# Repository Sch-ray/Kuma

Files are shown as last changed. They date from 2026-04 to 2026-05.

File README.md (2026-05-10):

Welcome here, and thank you all for your support. This is the public directory of the KUMA project, where some files will be gradually open-sourced.

> [!IMPORTANT]
> Statement: If you like the FlipperZero project and have sufficient financial ability, please purchase the original device through official channels. Building such a strong community is not easy, and we appreciate that they have open-sourced a large amount of materials. My device is not intended for counterfeiting or piracy. It includes targeted modifications and uses a completely new exterior design for clear distinction. The enclosure is fully incompatible with the original device. The purpose is to create a more affordable device and promote better development of the project.

> [!IMPORTANT]
> Additional statement: The device is intended only for legal technical learning and lawful analysis and testing by professionals (you should know what you are doing).

[Shell_Modell](./Shell_Model)
The shell model files are now available. Now you can print more beautiful and personalized cases for yourself 😎! 

This is my YouTube channel
[Youtube](https://www.youtube.com/channel/UCHENkZK1oac_hoAVk4aAufA)

This is my BiliBili channel
[BiliBili](https://space.bilibili.com/150167463)

If you are seeking business collaboration or advice regarding a project, you can contact me via email.
[Email](xiao_hei666@yeah.net)

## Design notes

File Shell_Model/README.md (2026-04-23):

Welcome here, and thanks for your support!
If you own a 3D printer, you can now print a ⭐ better-looking and 😎 more personalized enclosure for yourself!
And if you have enough time, you can also choose finer print settings for higher quality results.

I used **PETG** material for printing. With proper printer settings, the result should come out pretty good.

> [!WARNING]
> Warning: Disassembling the enclosure may damage your device. You are responsible for any risks or consequences.

> [!IMPORTANT]
> Disclaimer: If you like the FlipperZero project and have the financial ability, please consider purchasing the original device through official channels. Building such a strong community is not easy, and they have open-sourced a large amount of valuable information.
> My device is **not** intended for counterfeiting or piracy. It includes targeted modifications and a completely new appearance for clear differentiation. The enclosure and structural parts are **fully incompatible** with the original device.
> The goal is to create a more affordable device and help the project ecosystem grow.

> [!IMPORTANT]
> Additional Disclaimer: This device is intended only for legal technical learning, professional research, and lawful analysis/testing purposes (you should know what you are doing).

---

### Before printing your own enclosure, you should know:

1. Due to cost constraints and limited development resources, the structure is not perfect. Disassembly carries some risk. Please read the instructions carefully and make sure you have steady hands and a solder station.

2. Replacing and installing the enclosure requires hands-on skills. Make sure you are confident before starting. Any damage caused during disassembly is your own responsibility.

3. Make sure your 3D printer build plate is clean and has good adhesion. Some narrow lines and characters require a well-prepared print surface.
   (My early prints failed many times because the build plate wasn’t clean enough.)

4. Be mentally prepared — since the device is hand-assembled and soldered, there will be visible soldering marks inside 🙄.

---

### File Description: Latest Version [V1](./V1)

<sub>*This directory includes 5 parts: Top Shell, Middle Layer, Bottom Shell, Buttons, and Light Pipe.*</sub>

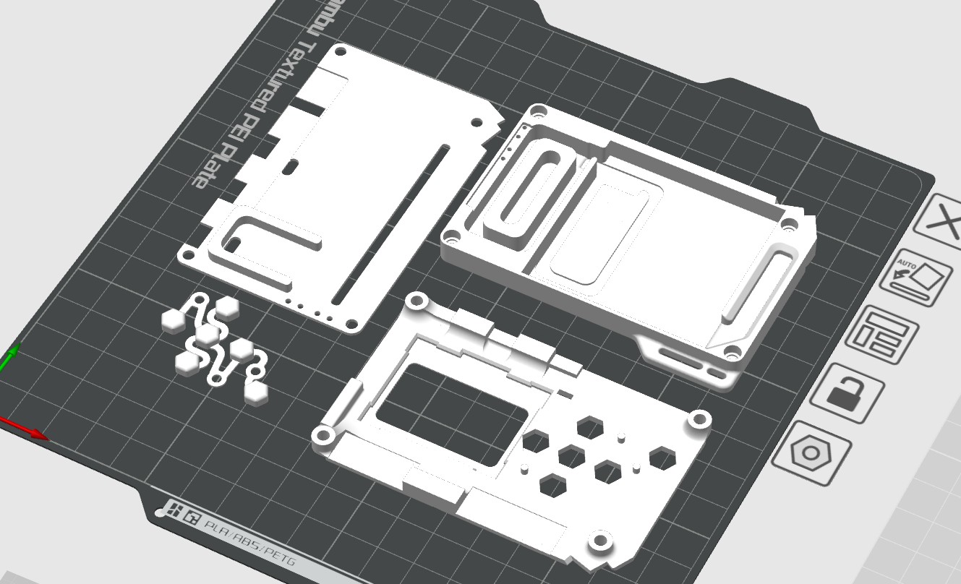
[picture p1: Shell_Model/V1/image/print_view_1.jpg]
print\_view\_1

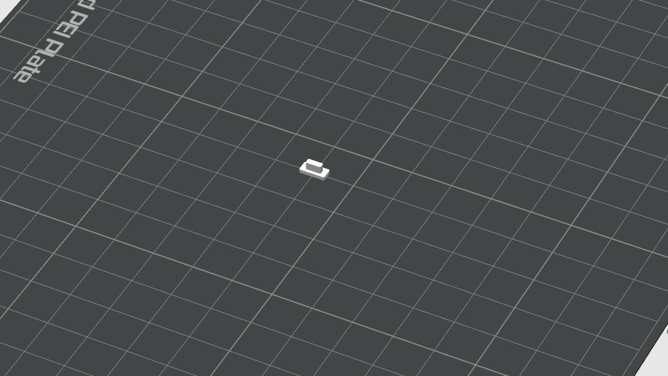
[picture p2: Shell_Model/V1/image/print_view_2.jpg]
print\_view\_1


> [!TIP]
> `LED_Light_Pipe.step` is the front light pipe of the device and should be printed using transparent filament.
> If you don’t have transparent material, you can leave it empty, fill it with semi-transparent glue, or reuse the light pipe from an existing enclosure.

---

### Disassembly and Assembly Instructions:

> [!TIP]
> Before disassembly, touch a grounded metal object nearby or use an anti-static wrist strap to avoid damaging the circuit board with static electricity.

---

**1. Remove the Top Shell**

On the front side of the device, you will find four screws at the corners. Remove them using a hex screwdriver.

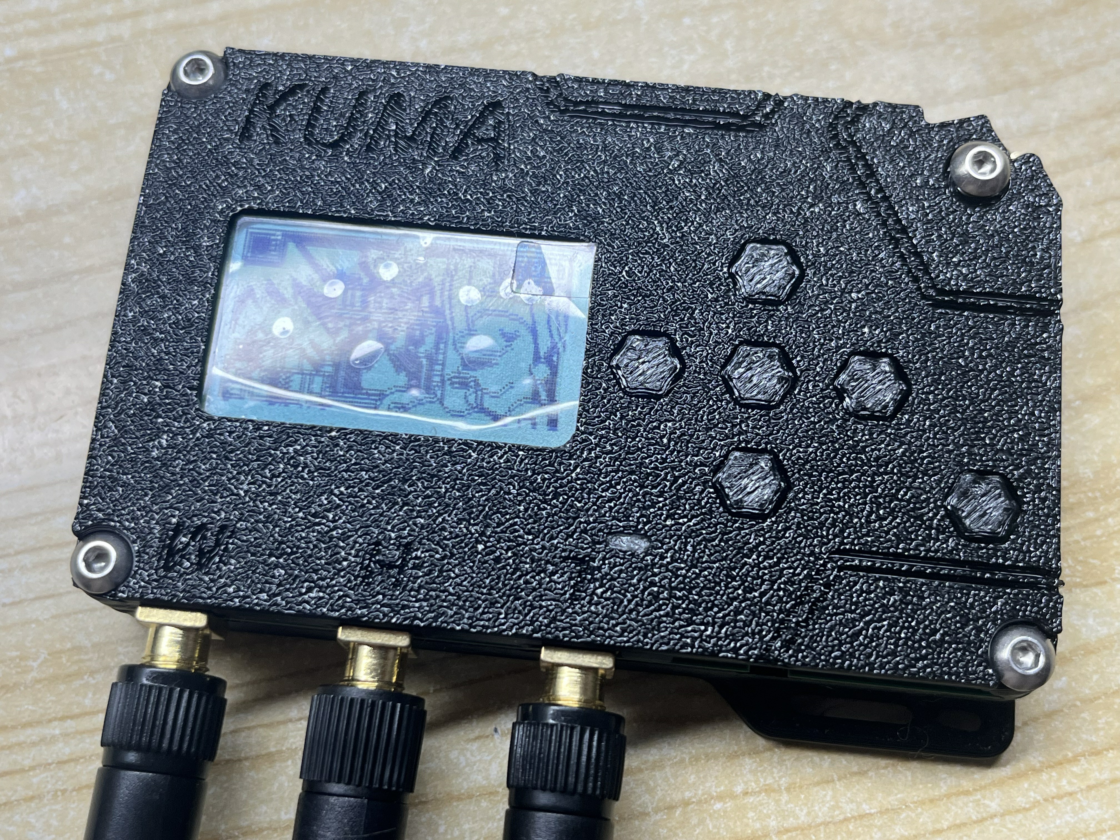
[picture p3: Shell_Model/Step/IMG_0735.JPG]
Step\_1


You will then see the circuit board.

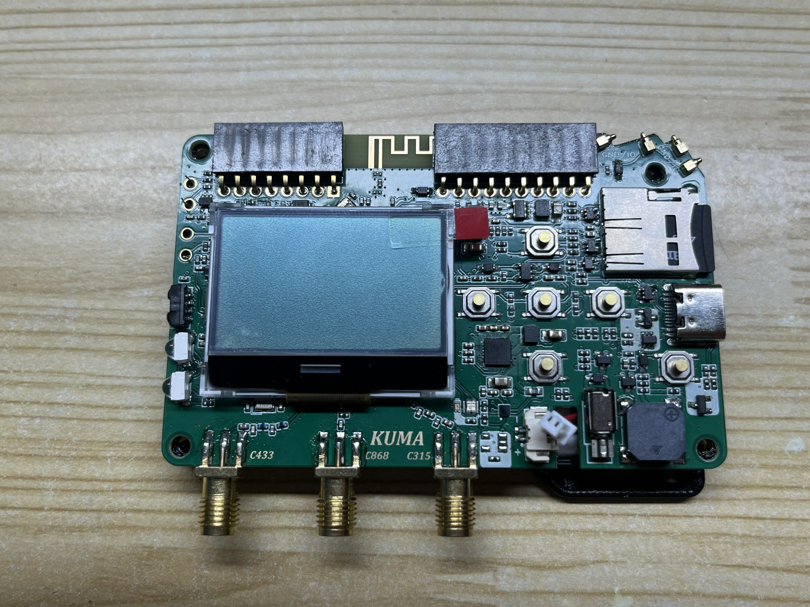
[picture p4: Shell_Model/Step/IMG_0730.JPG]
Step\_1


---

**2. Disconnect the Cable**

Use tweezers or your fingernail to disconnect the power connector located at the lower-right side of the PCB.

> [!TIP]
> If you use metal tweezers, be careful not to short-circuit anything.

Remove the four small screws at the upper-left corner using a screwdriver.

> [!TIP]
>To ensure a stable connection, the method has been changed to welding. If you received the equipment after May 2026, it is of the welding type. In that case, you need to use a soldering iron to remove it.

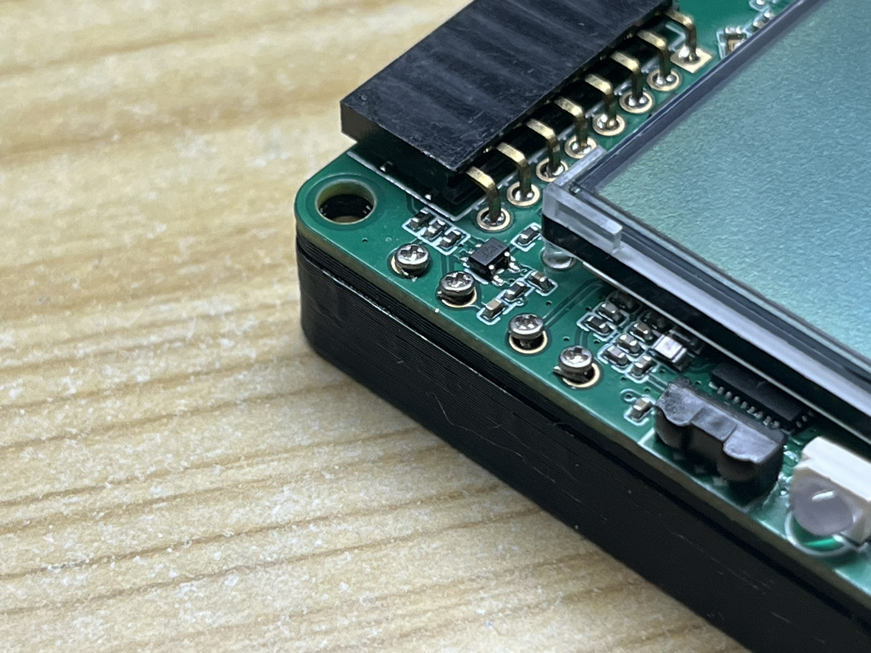
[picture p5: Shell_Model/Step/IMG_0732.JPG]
Step\_1

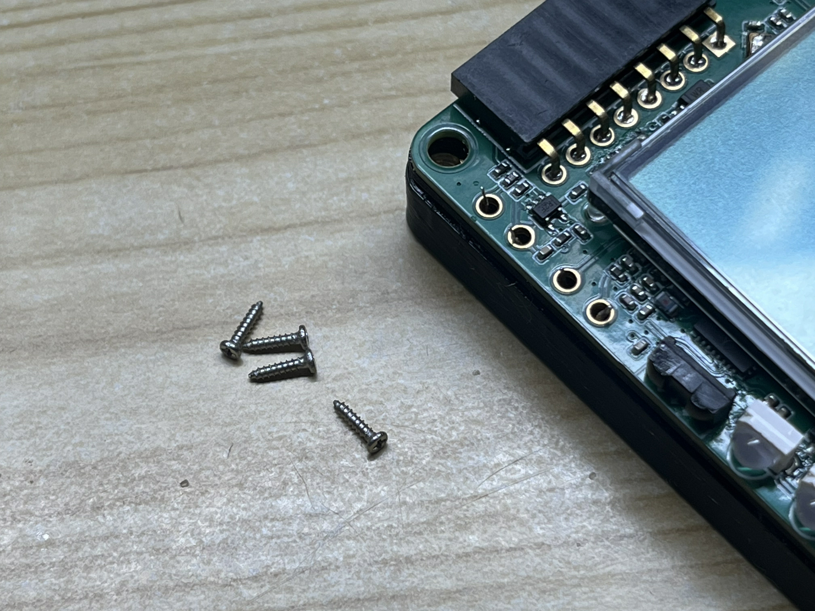
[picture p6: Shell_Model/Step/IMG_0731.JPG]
Step\_1


---

**3. Remove the Main Board**

Take out the main board.
This is what the back side looks like:

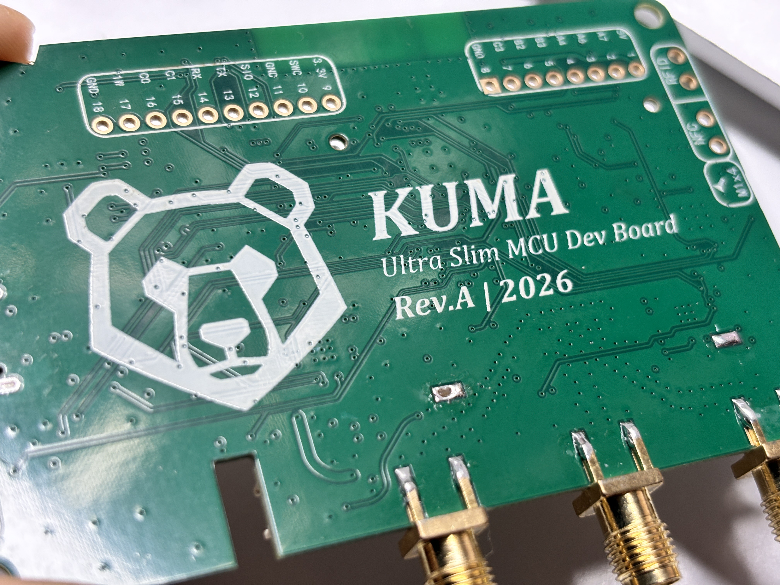
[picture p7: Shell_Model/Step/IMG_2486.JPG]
Step\_1


---

**4. Remove the Coil**

Remove the middle layer, then take out the battery.

You will notice that the coil wires pass through four small holes at the upper-left corner of the middle layer part:

* The **upper two holes** contain the **red wires**
* The **lower two holes** contain the **yellow wires**

Make sure not to mix them up during reassembly.

> [!TIP]
> RFID and NFC use AC signals, so coil polarity does not matter.
> Just make sure the top holes use the red wires, and the same logic applies to the yellow wires.

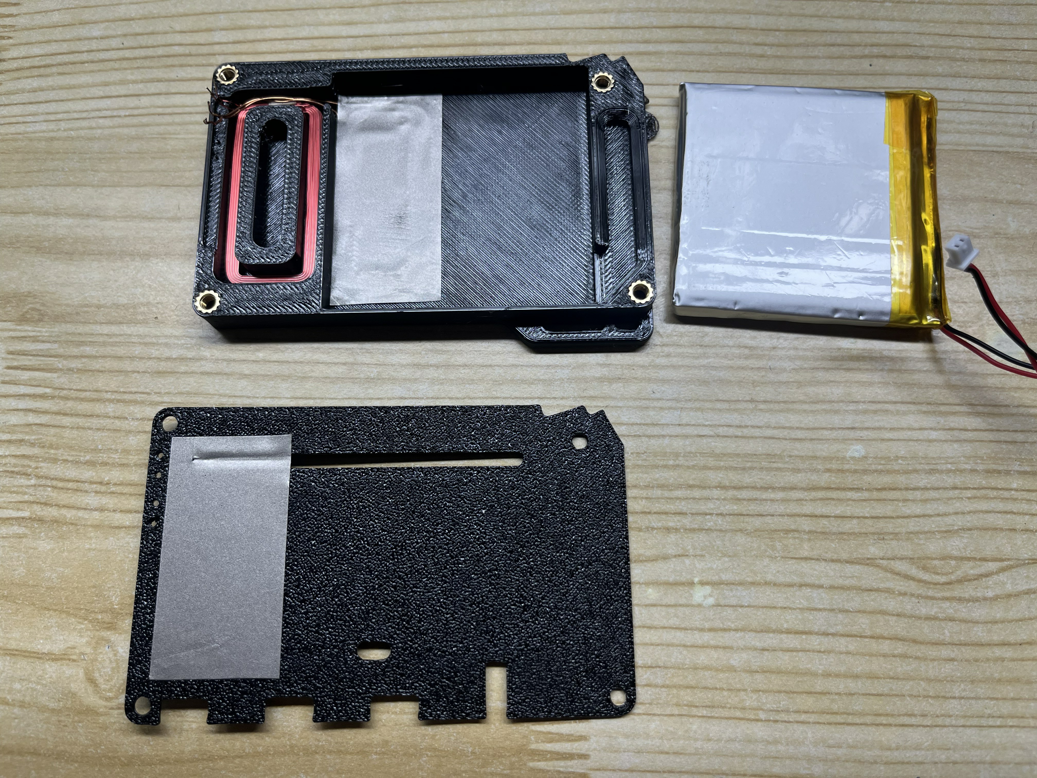
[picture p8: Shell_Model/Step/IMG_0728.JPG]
Step\_1


You will also find a magnetic shielding sticker under the battery. Carefully peel it off using tweezers.

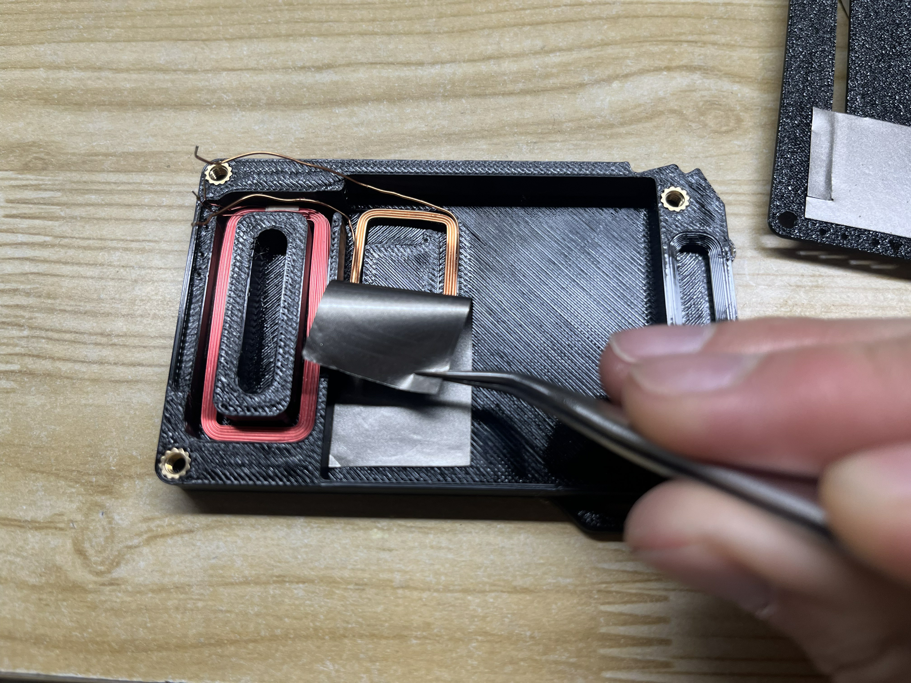
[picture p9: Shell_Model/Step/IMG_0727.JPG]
Step\_1


When fixing the red coil earlier, I added a small piece of double-sided tape underneath to prevent movement. You only need to gently pry it up to remove the coil.

> [!TIP]
> During disassembly, avoid scratching the insulation coating on the coil wire.
> Damage may cause short circuits between windings and affect read/write performance.

---

**5. Recover the Nuts**

If you don’t have heat-set threaded inserts, you can reuse the ones from the old enclosure.

Use a lighter or soldering iron to locally heat the area, then pry the nuts out with tweezers.

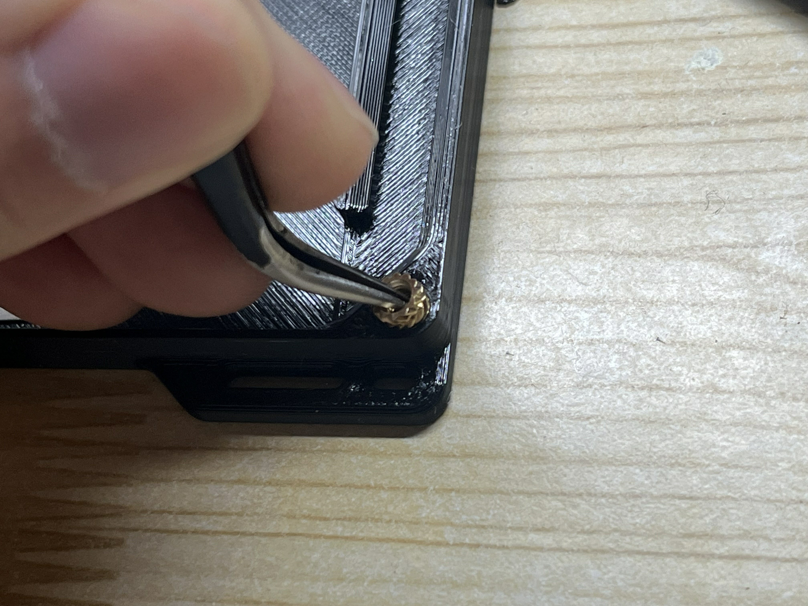
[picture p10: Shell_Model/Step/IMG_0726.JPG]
Step\_1


---

If you completed all the steps above — congratulations, disassembly is finished.

Now simply repeat all steps **in reverse order** to assemble everything into the new enclosure.

---

**6. Assembly Notes**

When reconnecting the coil:

If you have a soldering iron, it is strongly recommended to solder the connection for better reliability.

If not, you may continue using screws — but do **not** tighten them too much.
If 100% represents maximum tightness, stop at about **75%**.
Over-tightening can easily crush and break the wires (I’ve damaged quite a few this way 🙄).

Step\_1

In the final step, the top shell includes a raised feature that presses against the four screws, preventing them from loosening or falling out.

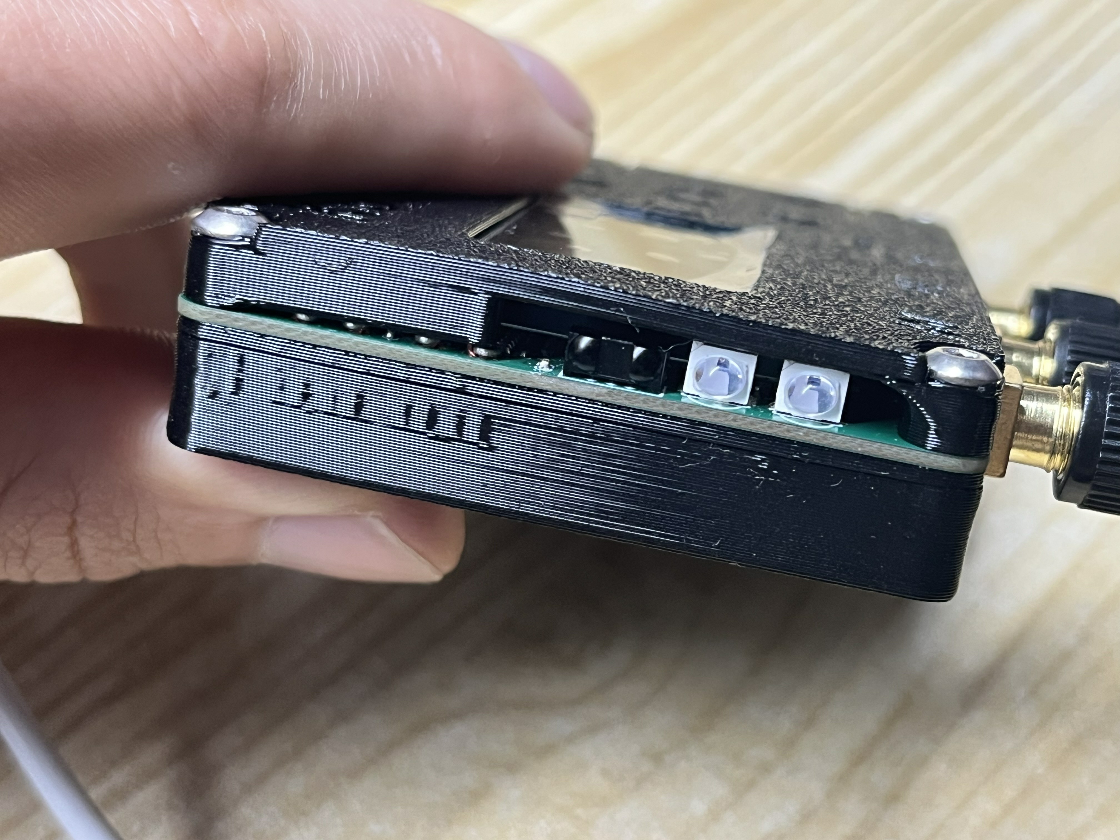
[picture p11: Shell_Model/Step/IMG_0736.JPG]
Step\_1


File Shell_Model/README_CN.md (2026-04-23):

欢迎来到这里，感谢大家支持，如果你有一台3D打印机，现在你可以为自己打印更漂亮⭐更具个人特色😎的外壳!并且如果你有足够的时间，可以选择更精细的打印精度。

我在打印时使用了PETG材料，如果打印机设置正确的话，打印效果还不错。

> [!WARNING]
> 警告，拆卸壳体有可能损坏设备，你需要自己承担后果。

> [!IMPORTANT]
> 声明：如果你喜欢FlipperZero项目，并且拥有足够的经济能力，可以通过官方渠道购买原版设备，构建如此强大的社区并不容易，感谢他们开源了大量资料。我的设备并不是为了伪造或者盗版，而是针对性进行了一些修改，且使用了全新的外观用于区分，与原版设备的外壳、结构零件等完全不兼容。目的是制作更廉价的设备，使项目得到更好的发展。

> [!IMPORTANT]
> 再次声明：设备仅用作专业人员的合法技术学习和合法分析测试（你最好知道你自己在干什么）。

### 开始打印自己的外壳前，你需要知道：
1、由于成本的压缩，以及有限的能力，结构上并不是那么完美，拆装有风险，请仔细阅读说明，并且确保你有一个电烙铁和灵活的双手。

2、更换和安装外壳需要一定的动手能力，开始之前确定你可以搞定，不要弄坏你的设备，因为拆卸导致的后果，由你自己承担。

3、确保3D打印机的打印板干净，富有粘性，因为打印一些窄线条和字符的时候，对打印板有较高的要求（我最初打印的时候因为打印板不够干净，粘性较差，失败了很多次）。

4、做好心理准备，由于是手工组装焊接的，所以内部会有焊接的痕迹~🙄

### 文件说明：目前最新版本[V1](./V1)

<sub>*这个目录包括5个零件：顶部壳体、中间层，底部壳体、按键、导光柱。*</sub>
print_view_1
print_view_1
> [!TIP]
> LED_Light_Pipe.step是设备正面的导光柱，需要使用透明耗材进行打印，如果没有可以空置，或者填充一些半透明的胶水。或者可以从现有的壳体上拆下来继续使用。

### 拆卸及组装说明：

> [!TIP]
> 拆卸之前，你可以触摸附近的接地金属，或者使用静电手环，避免静电损坏电路板。

**1、拆掉顶壳**

在设备正面，你可以看到边角处有4个螺丝，使用内六角螺丝刀拆下他们。
Step_1
然后就会看到电路板。
Step_1

**2、断开连接线**

使用镊子或者指甲，断开电路板右下方的电源连接插头。
> [!TIP]
> 如果你使用金属镊子，务必小心不要短路。

使用螺丝刀取下左上角的4颗小螺丝。

> [!TIP]
>为确保连接稳定，改为了焊接，如果你是在2026年5月份后得到的设备，是焊接方式的，你需要使用烙铁来拆除）。

Step_1
Step_1

**3、拿出主板**

将主板拿下来。这是主板背面的样子。
Step_1

**4、取出线圈**

将中间层也拿下来，然后电池也可以拿出来。这一步你会注意到线圈的导线穿过了中间层零件左上角的4个小孔，靠上的是两根红色的线，靠下的是两根黄色的线，等下装回去时不要搞错。

> [!TIP]
> 由于RFID和NFC是交流信号，所以线圈本身的线序不区分正反，也就是说：只要保证上面的两个孔是红色的线就行。黄色的同理。

Step_1
可以看到电池下方还有一片隔磁贴纸，使用镊子将其撕下来。
Step_1
需要注意的是在我进行红色线圈固定时，为了避免晃动，在下方使用了一点点双面胶，只需要轻轻翘一下，就可以将线圈拆下来。

> [!TIP]
> 拆卸过程中，小心不要刮坏线圈表明的绝缘漆，可能会导致线圈之间异常短路，影响读写效果。

**5、回收螺母**

如果你没有热熔螺母，你可以将旧壳子上面的拆下来，你需要使用打火机或者电烙铁等工具进行局部加热，然后使用镊子将螺母翘出来。
Step_1

如果你完成了上述步骤的话，恭喜你拆卸完成。

现在，把这些步骤再反向重复一遍，装回到新的壳体里。

**6、组装注意事项**

在连接线圈这一步，如果你有电烙铁，强烈建议使用电烙铁进行固定，更加可靠。如果没有的话，你可以继续使用螺丝，但是务必小心，不要把螺丝拧的太紧，如果100%是最紧，那么只需要拧到75%就可以了，不然很容易把导线挤压断裂（我弄坏过很多次~🙄）。

Step_1
在最后一步时，顶部壳体这里会有一个凸台，刚好可以下压住这四个螺丝，避免螺丝晃动或者脱落。
Step_1

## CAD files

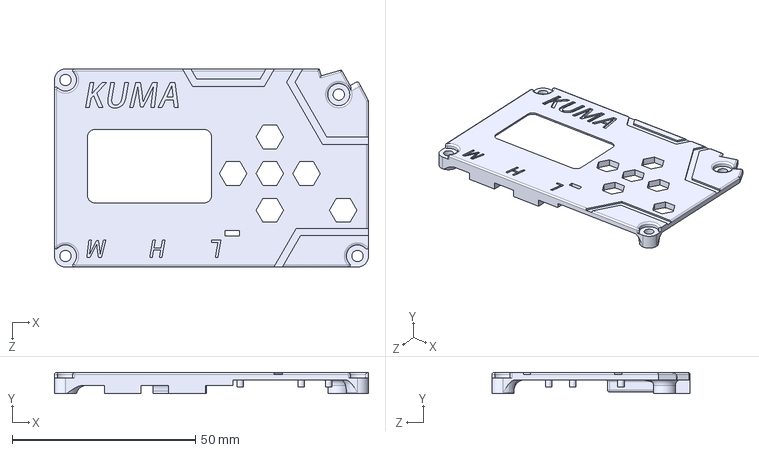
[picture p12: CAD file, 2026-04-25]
Shell_Model/V1/Shell_Top.STEP
85.6 x 5.75 x 54.0 mm

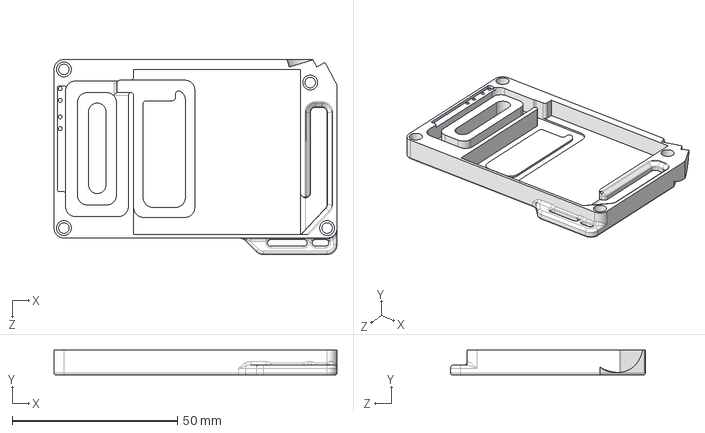
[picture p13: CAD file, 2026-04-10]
Shell_Model/V1/Shell_Button.STEP
85.6 x 7.50 x 59.0 mm

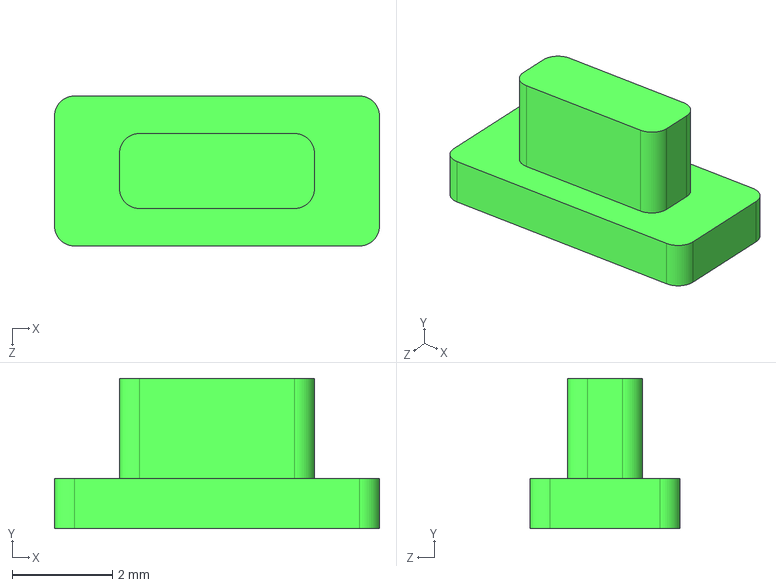
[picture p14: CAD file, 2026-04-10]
Shell_Model/V1/LED_Light_Pipe.STEP
6.50 x 3.00 x 3.00 mm

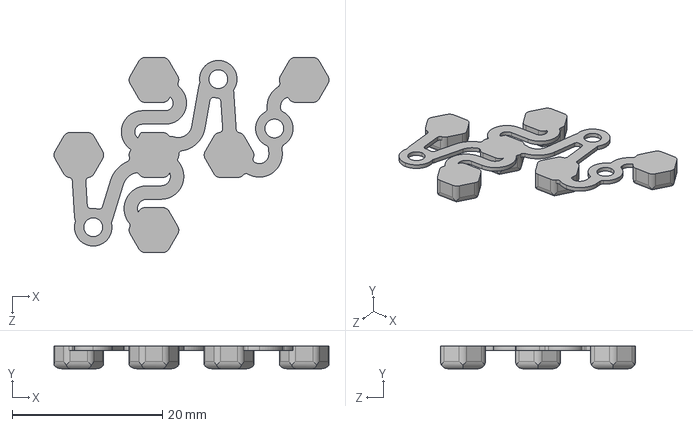
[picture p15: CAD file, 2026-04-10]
Shell_Model/V1/Botton.step
36.6 x 3.00 x 26.0 mm

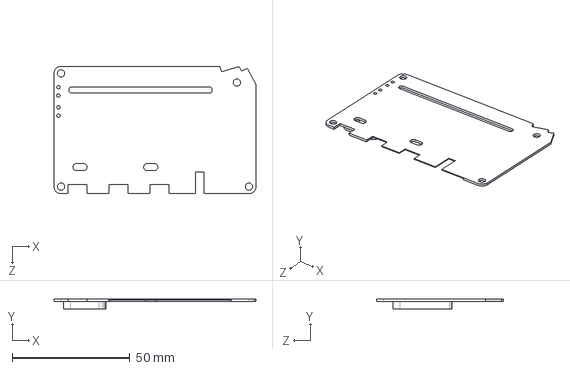
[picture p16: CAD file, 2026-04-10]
Shell_Model/V1/Shell_Middle.STEP
85.6 x 4.20 x 54.0 mm

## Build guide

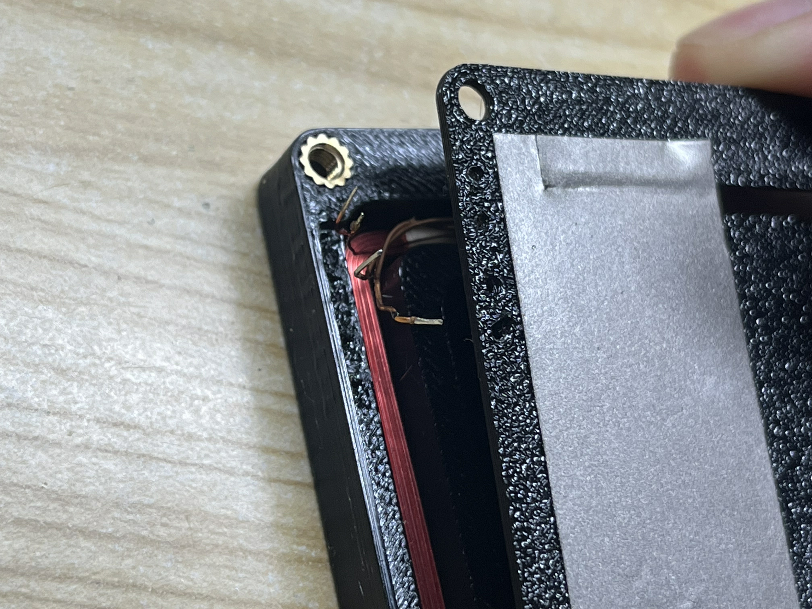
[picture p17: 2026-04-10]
Shell_Model/Step/IMG_0729.JPG
